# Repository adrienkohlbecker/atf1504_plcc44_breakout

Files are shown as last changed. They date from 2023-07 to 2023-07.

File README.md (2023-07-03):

# ATF1504 Breakout

Breakout board for Atmel's AFT1504 and ATF1502 CPLDs in a through-hole PLCC-44 socket. The size is friendly for breadboard use, with two rows of holes left available on each side of the breadboard for wires to come in.

## Board

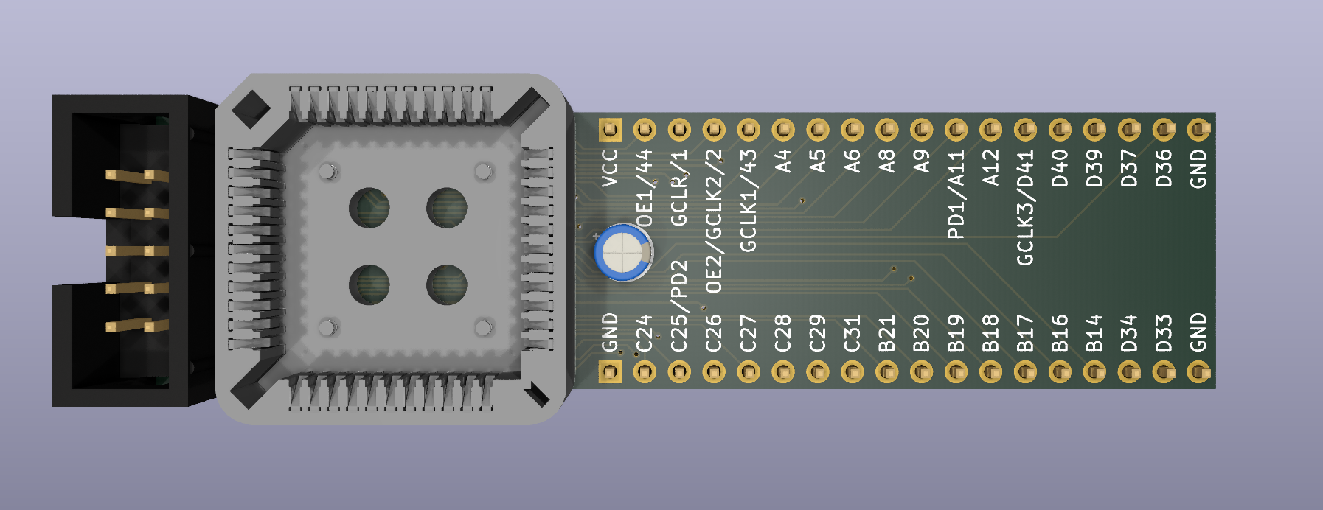
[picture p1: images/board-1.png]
board-1


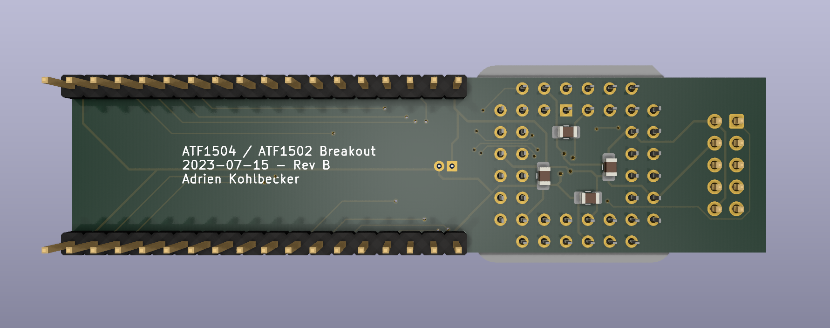
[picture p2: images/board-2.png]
board-2


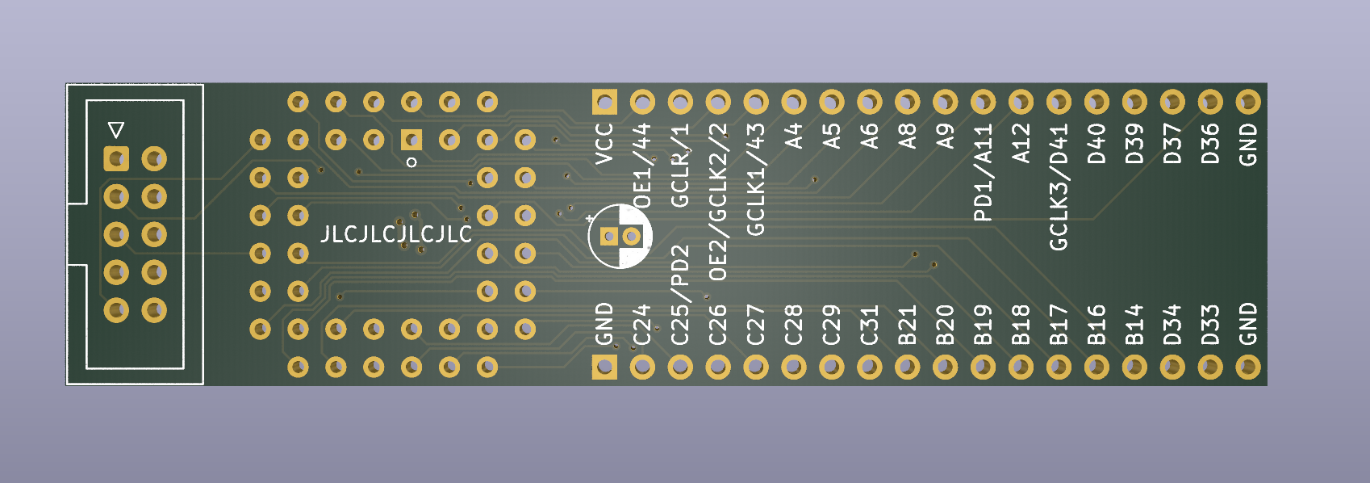
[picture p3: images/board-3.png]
board-3


## Schematic

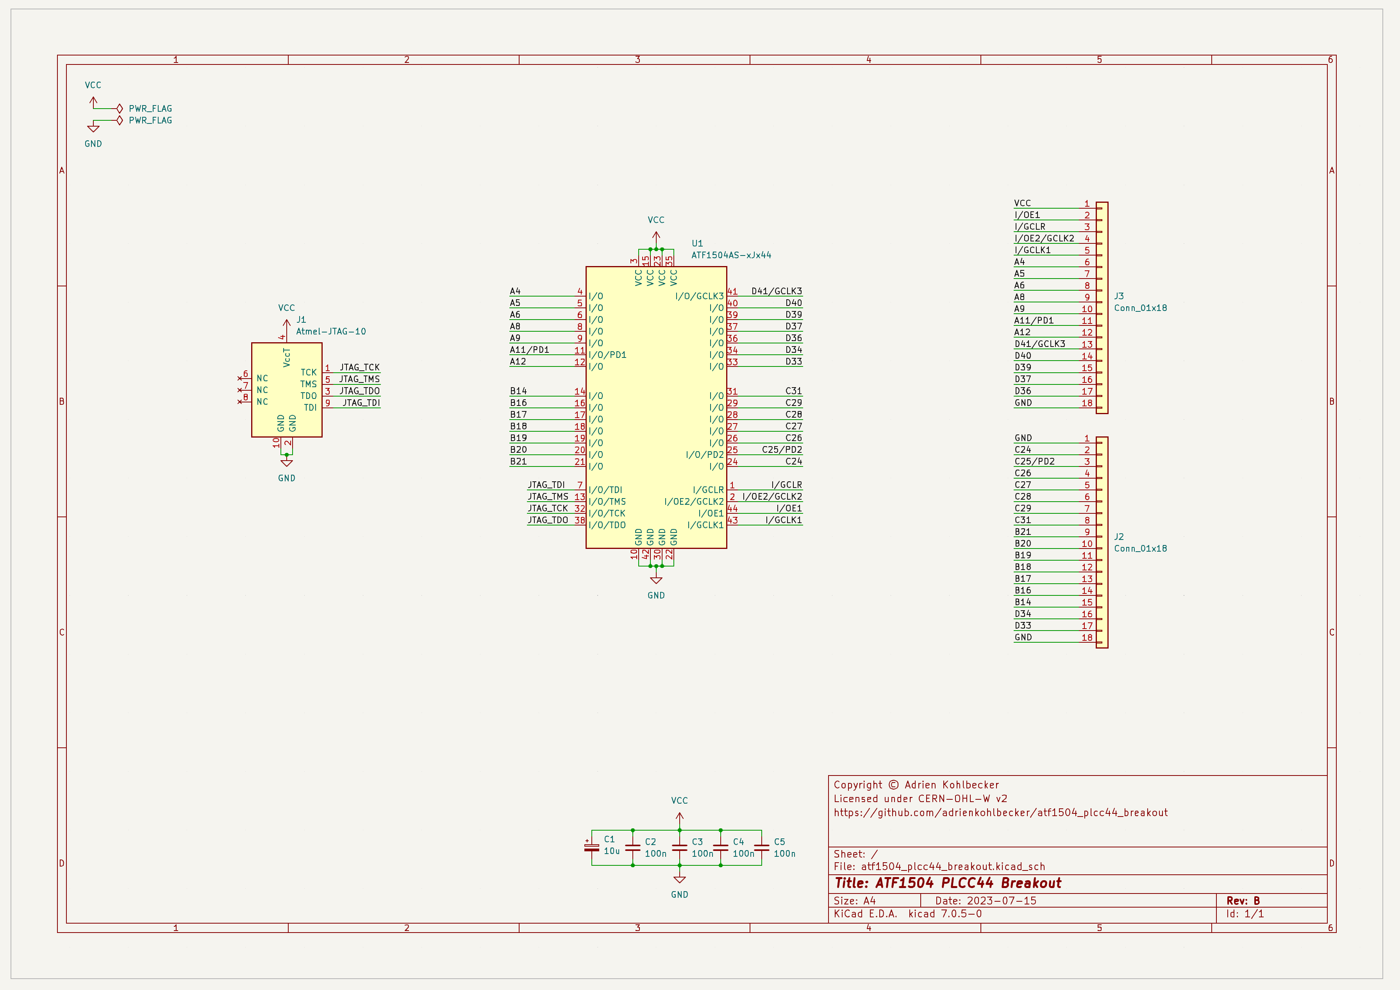
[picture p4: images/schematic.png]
schematic


## BOM

| Refs | Qty | Component | Description |
| ----- | --- | ---- | --- |
| C1 | 1 | 10u | Polarized capacitor, through hole D4.0mm P1.5mm |
| C2, C3, C4, C5 | 4 | 100n | Ceramic capacitor, SMD 0805 |
| J1 | 1 | Atmel-JTAG-10 | Atmel 10-pin JTAG connector, 2x5 IDC |
| J2, J3 | 2 | Conn_01x18 | Generic connector, single row, 01x18 |
| U1 | 1 | ATF1504AS-xJx44 | Microchip CPLD, in through hole PLCC-44 socket |

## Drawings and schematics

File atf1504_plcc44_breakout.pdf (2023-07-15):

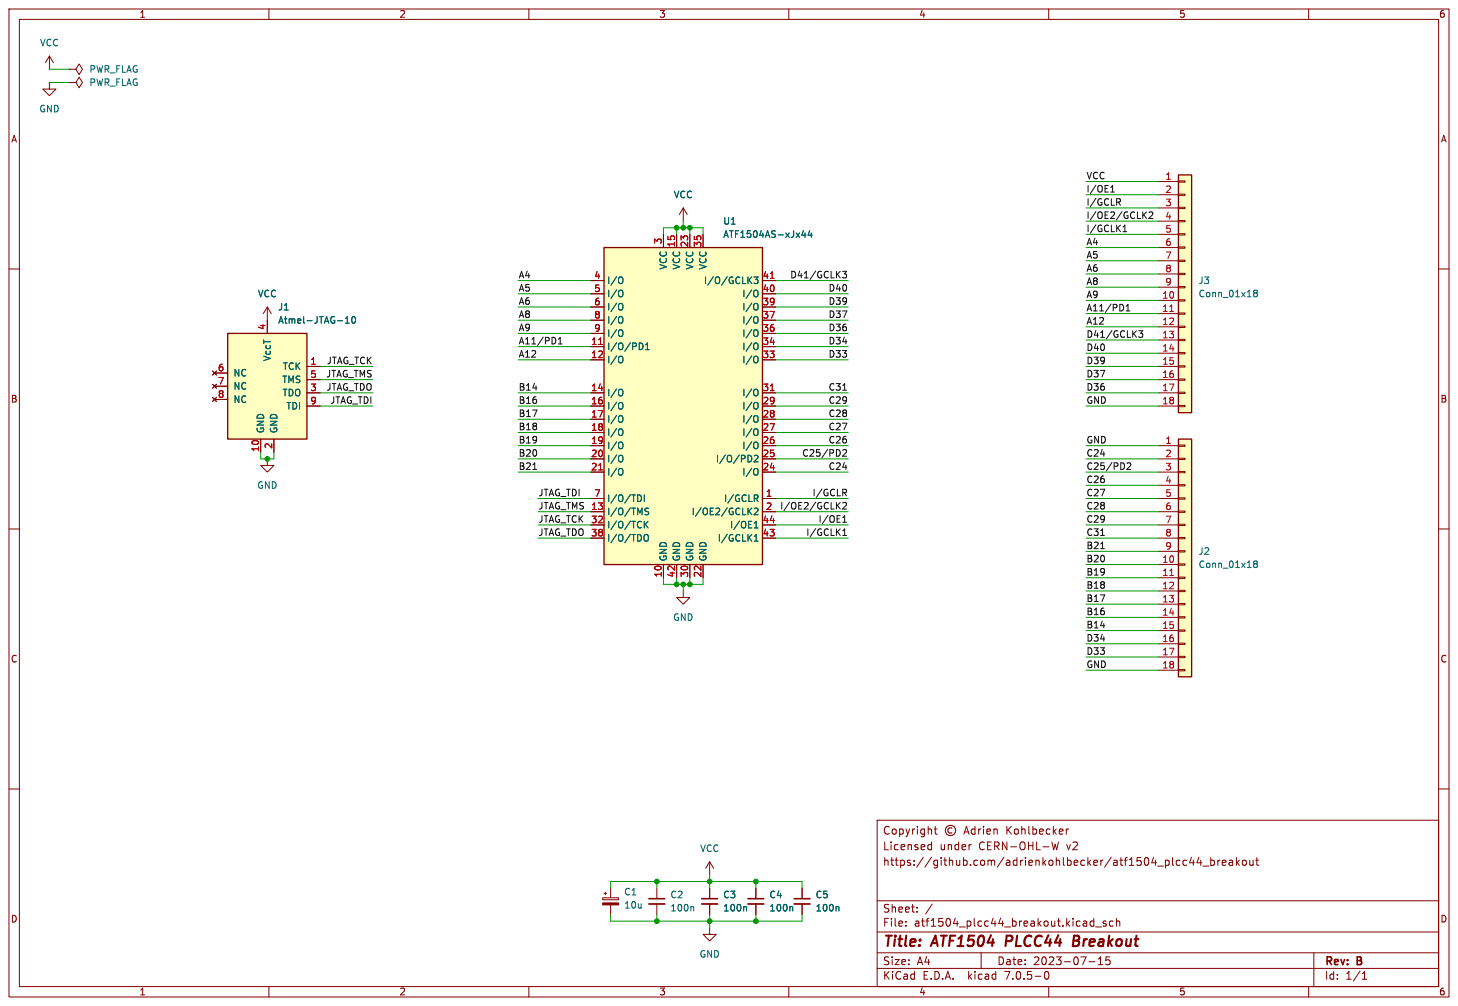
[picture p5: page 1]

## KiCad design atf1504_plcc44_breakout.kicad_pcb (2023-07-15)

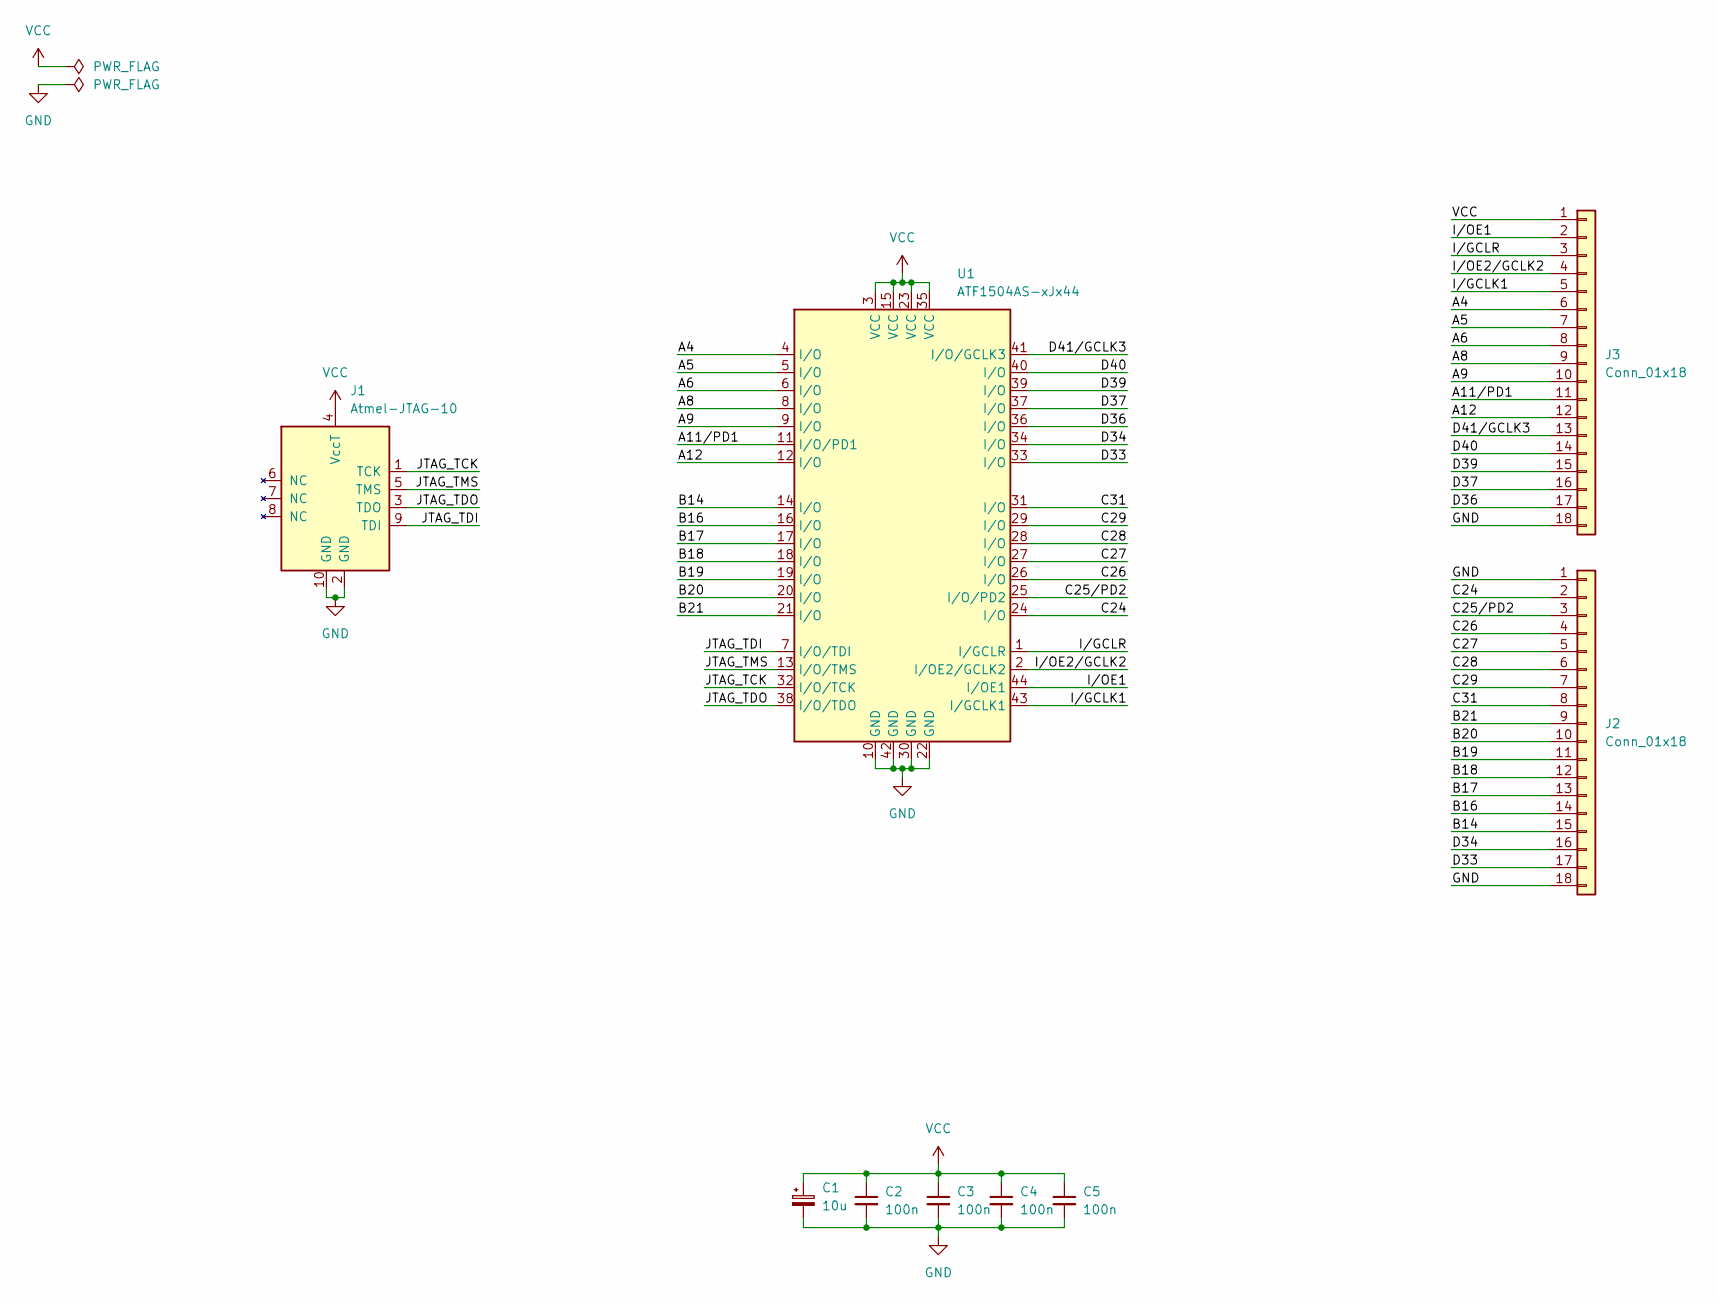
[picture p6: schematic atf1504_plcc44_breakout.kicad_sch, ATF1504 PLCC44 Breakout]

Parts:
C1: 10u; CP_Radial_D4.0mm_P1.50mm
C2, C3, C4, C5: 100n; C_0805_2012Metric_Pad1.18x1.45mm_HandSolder
J1: Atmel-JTAG-10; IDC-Header_2x05_P2.54mm_Vertical
J2, J3: Conn_01x18; PinHeader_1x18_P2.54mm_Vertical
U1: ATF1504AS-xJx44; PLCC-44_THT-Socket

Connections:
/A4: J3.6, U1.4 (I/O)
/A5: J3.7, U1.5 (I/O)
/A6: J3.8, U1.6 (I/O)
/A8: J3.9, U1.8 (I/O)
/A9: J3.10, U1.9 (I/O)
/A11/PD1: J3.11, U1.11 (I/O/PD1)
/A12: J3.12, U1.12 (I/O)
/B14: J2.15, U1.14 (I/O)
/B16: J2.14, U1.16 (I/O)
/B17: J2.13, U1.17 (I/O)
/B18: J2.12, U1.18 (I/O)
/B19: J2.11, U1.19 (I/O)
/B20: J2.10, U1.20 (I/O)
/B21: J2.9, U1.21 (I/O)
/C24: J2.2, U1.24 (I/O)
/C25/PD2: J2.3, U1.25 (I/O/PD2)
/C26: J2.4, U1.26 (I/O)
/C27: J2.5, U1.27 (I/O)
/C28: J2.6, U1.28 (I/O)
/C29: J2.7, U1.29 (I/O)
/C31: J2.8, U1.31 (I/O)
/D33: J2.17, U1.33 (I/O)
/D34: J2.16, U1.34 (I/O)
/D36: J3.17, U1.36 (I/O)
/D37: J3.16, U1.37 (I/O)
/D39: J3.15, U1.39 (I/O)
/D40: J3.14, U1.40 (I/O)
/D41/GCLK3: J3.13, U1.41 (I/O/GCLK3)
/I/GCLK1: J3.5, U1.43 (I/GCLK1)
/I/GCLR: J3.3, U1.1 (I/GCLR)
/I/OE1: J3.2, U1.44 (I/OE1)
/I/OE2/GCLK2: J3.4, U1.2 (I/OE2/GCLK2)
/JTAG_TCK: J1.1 (TCK), U1.32 (I/O/TCK)
/JTAG_TDI: J1.9 (TDI), U1.7 (I/O/TDI)
/JTAG_TDO: J1.3 (TDO), U1.38 (I/O/TDO)
/JTAG_TMS: J1.5 (TMS), U1.13 (I/O/TMS)
GND: C1.2, C2.2, C3.2, C4.2, C5.2, J1.2 (GND), J1.10 (GND), J2.1, J2.18, J3.18, U1.10 (GND), U1.22 (GND), U1.30 (GND), U1.42 (GND)
VCC: C1.1, C2.1, C3.1, C4.1, C5.1, J1.4 (VccT), J3.1, U1.3 (VCC), U1.15 (VCC), U1.23 (VCC), U1.35 (VCC)

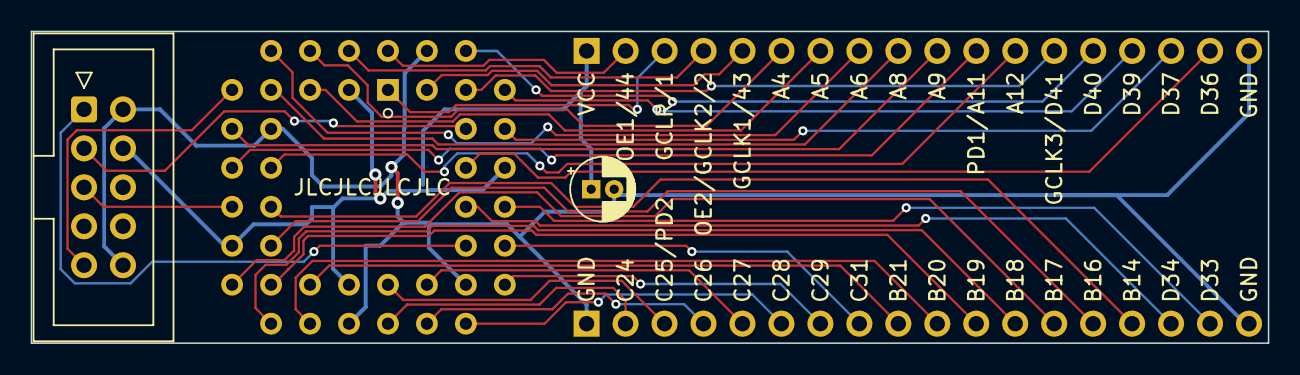
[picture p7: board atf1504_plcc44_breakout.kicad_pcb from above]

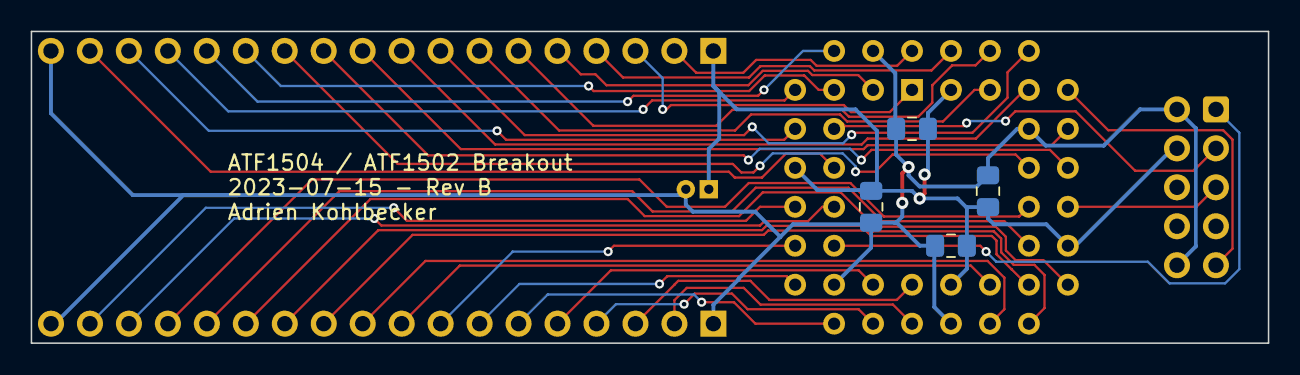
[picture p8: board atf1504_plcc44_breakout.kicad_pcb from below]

Board: 2 copper layers, 80.6 x 20.3 mm, 9 parts (6 on the bottom side), 38 nets.

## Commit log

2022-05-13 Initial template version
    [kicad_template.kicad_pcb, kicad_template.kicad_sch]
2022-05-13 Update PCB template
    [kicad_template.kicad_pcb, kicad_template.kicad_sch]
2023-06-20 First release
    [atf1504_plcc44_breakout-B_Cu.gbl, atf1504_plcc44_breakout-B_Mask.gbs, atf1504_plcc44_breakout-B_Paste.gbp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]
2023-07-03 Revert oscillator addition
    [atf1504_plcc44_breakout-B_Cu.gbl, atf1504_plcc44_breakout-B_Mask.gbs, atf1504_plcc44_breakout-B_Paste.gbp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]
2023-07-15 Add pin numbers for global inputs and re-order them
    [atf1504_plcc44_breakout-B_Cu.gbl, atf1504_plcc44_breakout-B_Mask.gbs, atf1504_plcc44_breakout-B_Paste.gbp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]

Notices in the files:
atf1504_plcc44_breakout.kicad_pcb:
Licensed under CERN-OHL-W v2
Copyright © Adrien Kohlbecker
